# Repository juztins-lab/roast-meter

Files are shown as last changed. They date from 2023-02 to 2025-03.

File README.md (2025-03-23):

<!--
repo name: roast-meter
description: DIY roast meter guide
github name:  Juztins-Lab
link: https://github.com/juztins-lab/roast-meter
logo path: assets/logo.png
screenshot: 
twitter: your_username
email: justin@skitlabs.net
-->

<!-- PROJECT SHIELDS -->
[][contributors-url]
[][forks-url]
[][stars-url]
[][issues-url]
[][license-url]
<!-- [![LinkedIn][linkedin-shield]][linkedin-url] -->

<!-- PROJECT LOGO -->
<br />
<p align="center">
    <a href="https://github.com/juztins-lab/roast-meter">
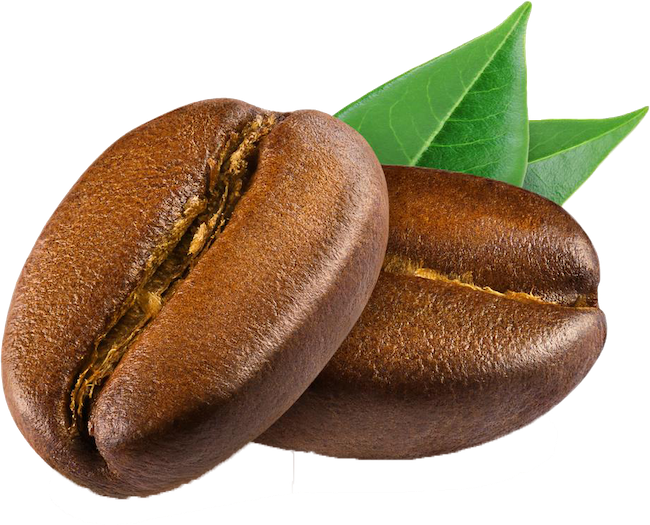
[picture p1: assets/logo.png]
        
    </a>
<h3 align="center"><a href="https://github.com/juztins-lab/roast-meter">Roast Meter</a></h3>
    <p align="center">
        An awesome DIY projects that will help you get better consistent roasts by measuring roast color between batches
        <br />
        <br />
        <a href="https://github.com/juztins-lab/roast-meter/issues">Report Bug</a>
        •
        <a href="https://github.com/juztins-lab/roast-meter/issues">Request Feature</a>
    </p>
</p>

<!-- TABLE OF CONTENTS -->
## Table of Contents

- [About The Project](#about-the-project)
- [Assembly Instructions](#assembly-instructions)
- [User Guide](#user-guide)
- [Calibration process](#calibration-process)
- [Roadmap](#roadmap)
- [Contributing](#contributing)
- [License](#license)
- [Contact](#contact)

<!-- ABOUT THE PROJECT -->
## About The Project

Starting into home roasting I've quickly realised the importance of a roast meter to evaluate the color of the coffee, this helps you better target different end temperature/time but retain the same level of color and see how it influences taste.

Here's why:
* Commercial grade roast meters are very expensive
* Chips and sensors are are readily available/cheap and easy to get going
* At the end of the guide you will have an ~100$ roast meter, that is consistent and can help you get the most out of your roast.

Check out our wiki for detailed instructions for assembly usage and calibration!

## Assembly Instructions
https://github.com/juztins-lab/roast-meter/wiki/Roast-Meter-Assembly-Instructions

## User Guide
https://github.com/juztins-lab/roast-meter/wiki/Roast-Meter-User's-Guide

## Calibration process
https://github.com/juztins-lab/roast-meter/wiki/Roast-Meter-User's-Guide#calibration-methods

<!-- ROADMAP -->
## Roadmap
* ~~Calibration against Agtron Gourmet Scale~~ (DONE)
* ~~Add battery, on/off button~~ (DONE)
* ~~Sensor calibration process - improved for consistency~~ (DONE)
* ~~Mobile application to store coffee roast information as well as roast level and history (bluetooth)~~ (BT version available but works with **external** web app)

See the [open issues](https://github.com/juztins-lab/roast-meter/issues) for a list of proposed features (and known issues).

<!-- CONTRIBUTING -->
## Contributing

Contributions are what make the open source community such an amazing place to be learn, inspire, and create. Any contributions you make are **greatly appreciated**.

1. Fork the Project
2. Create your Feature Branch (`git checkout -b feature/AmazingFeature`)
3. Commit your Changes (`git commit -m 'Add some AmazingFeature'`)
4. Push to the Branch (`git push origin feature/AmazingFeature`)
5. Open a Pull Request

<!-- LICENSE -->
## License

Distributed under the GNU License. See `LICENSE` for more information.

<!-- CONTACT -->
## Contact

Juztin - roastmeter@skitlabs.net

Project Link: [https://github.com/juztins-lab/roast-meter](https://github.com/juztins-lab/roast-meter)

<!-- MARKDOWN LINKS & IMAGES -->
<!-- https://www.markdownguide.org/basic-syntax/#reference-style-links -->
[contributors-shield]: https://img.shields.io/github/contributors/juztins-lab/roast-meter.svg?style=flat-square
[contributors-url]: https://github.com/juztins-lab/roast-meter/graphs/contributors
[forks-shield]: https://img.shields.io/github/forks/juztins-lab/roast-meter.svg?style=flat-square
[forks-url]: https://github.com/juztins-lab/roast-meter/network/members
[stars-shield]: https://img.shields.io/github/stars/juztins-lab/roast-meter.svg?style=flat-square
[stars-url]: https://github.com/juztins-lab/roast-meter/stargazers
[issues-shield]: https://img.shields.io/github/issues/juztins-lab/roast-meter.svg?style=flat-square
[issues-url]: https://github.com/juztins-lab/roast-meter/issues
[license-shield]: https://img.shields.io/github/license/juztins-lab/roast-meter.svg?style=flat-square
[license-url]: https://github.com/juztins-lab/roast-meter/blob/master/LICENSE.txt
[product-screenshot]: images/screenshot.png

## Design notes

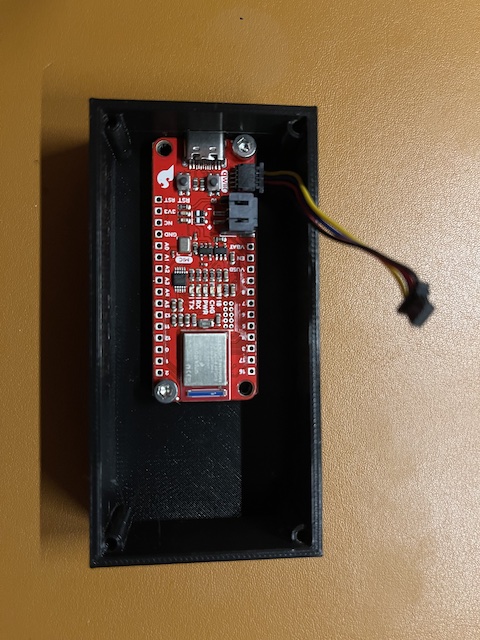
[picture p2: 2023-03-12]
assets/Case with board mounted.jpg

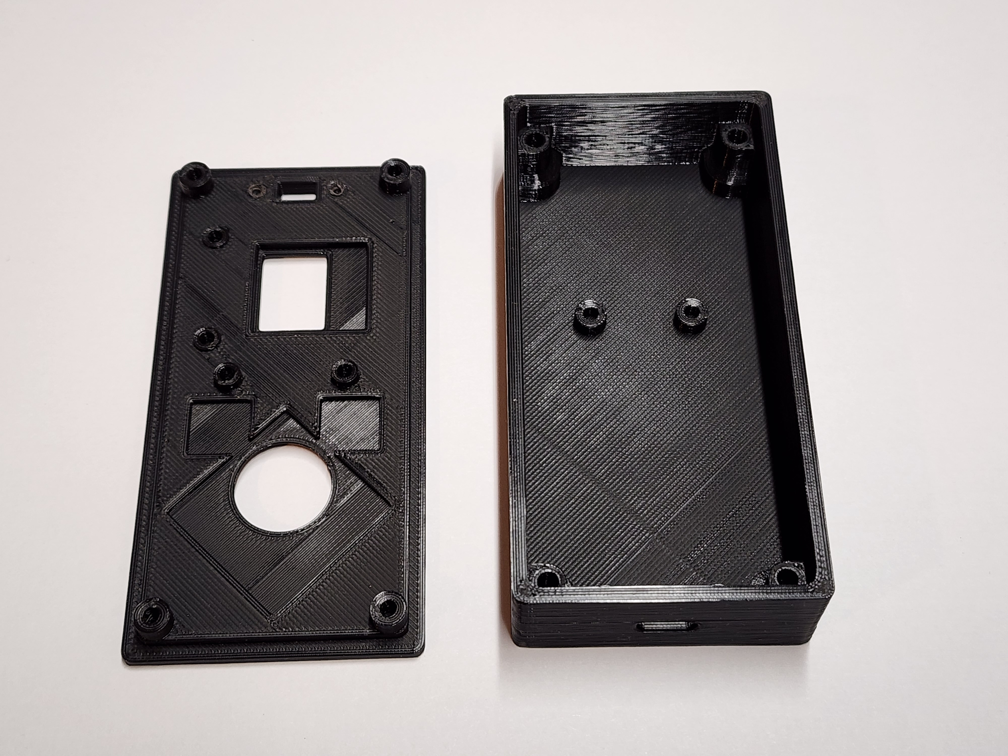
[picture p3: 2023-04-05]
assets/RM Case.jpg

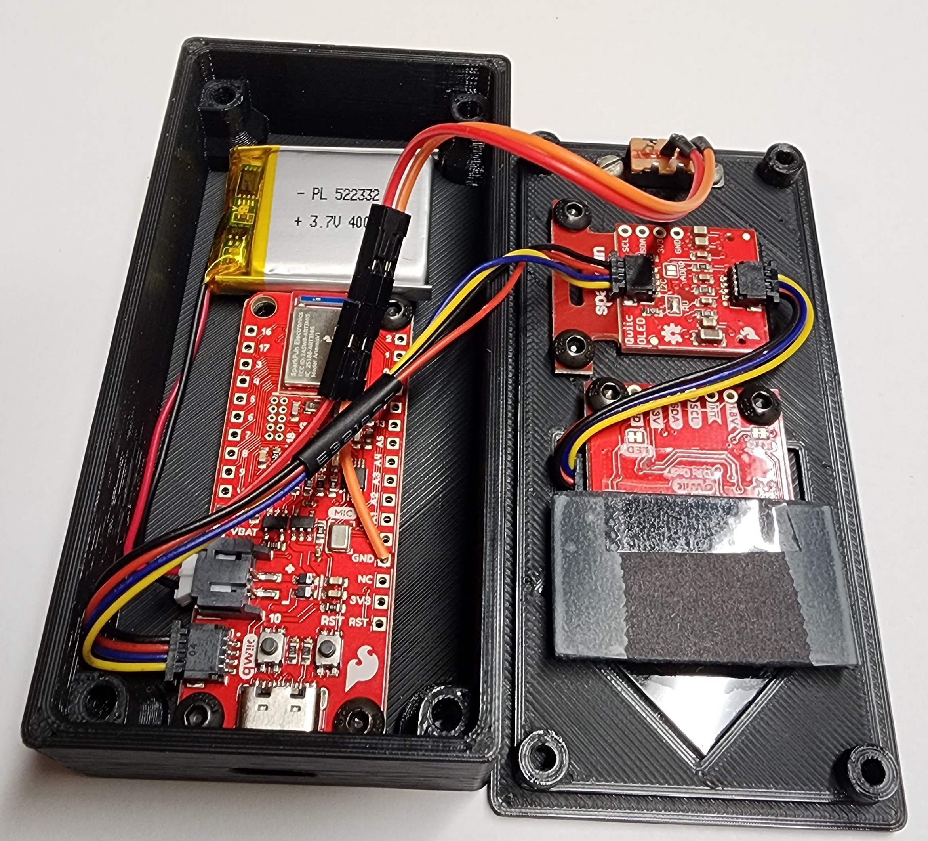
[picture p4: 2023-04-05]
assets/RM switch and battery.jpg

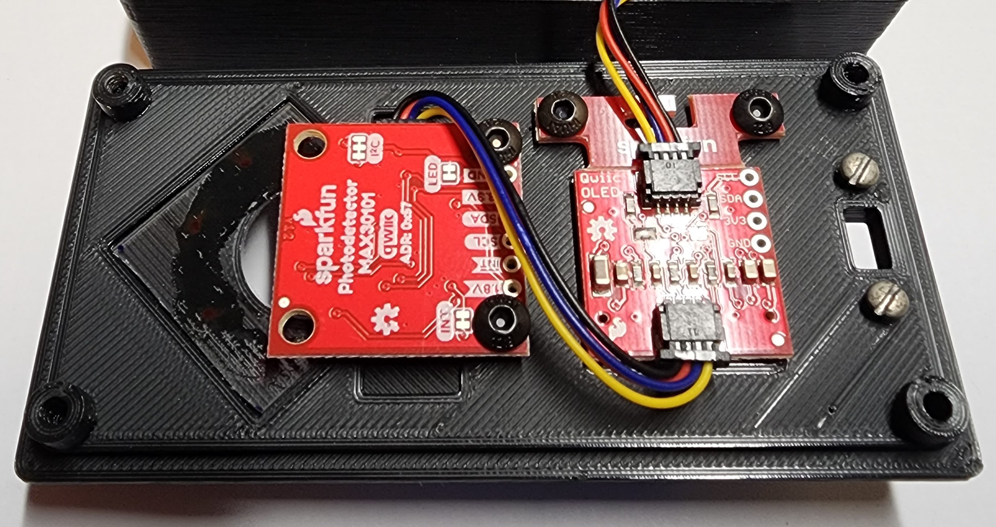
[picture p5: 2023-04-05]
assets/RM Lid CLose up.jpg

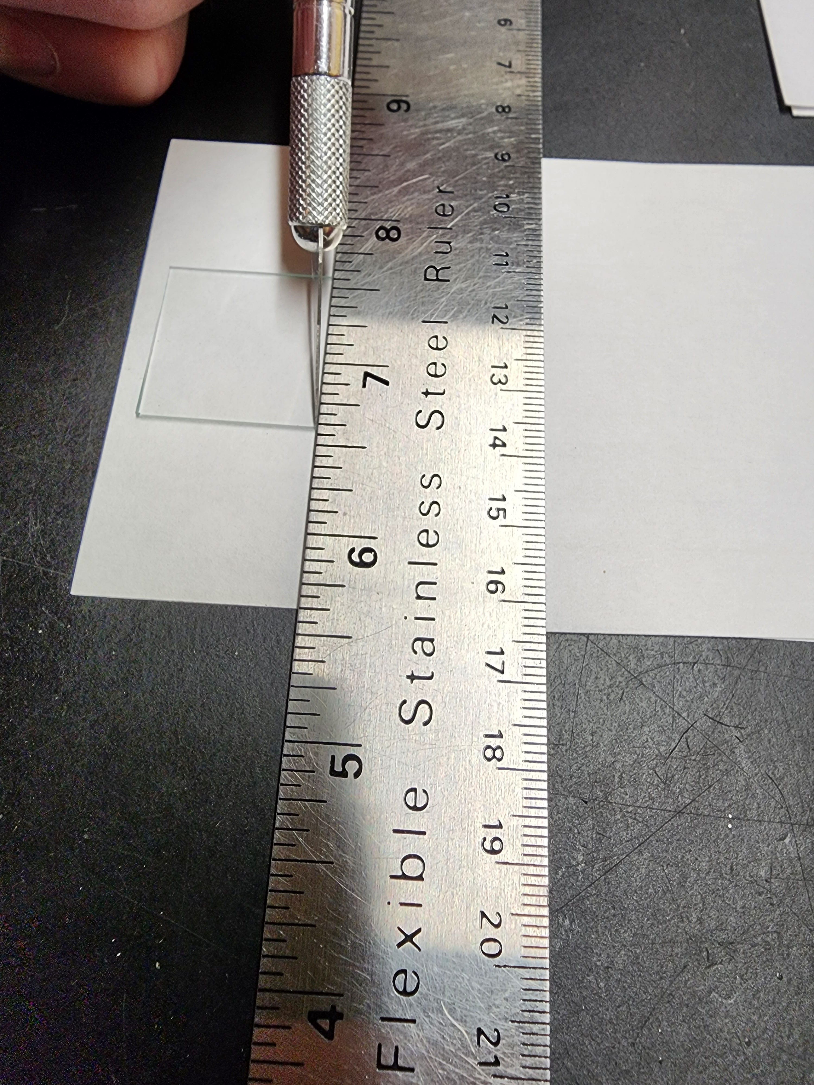
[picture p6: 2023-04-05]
assets/Cut Glass.jpg

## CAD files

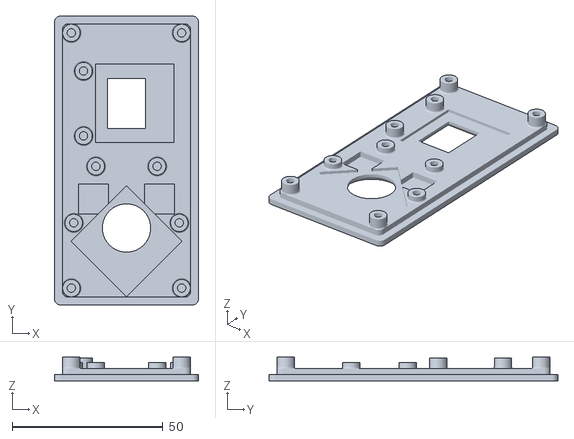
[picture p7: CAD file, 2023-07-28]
3D Print/Roast-Meter-Sensor-Tray-LID-NO-SWITCH-20230727.stl
47.8 x 95.8 x 7.80

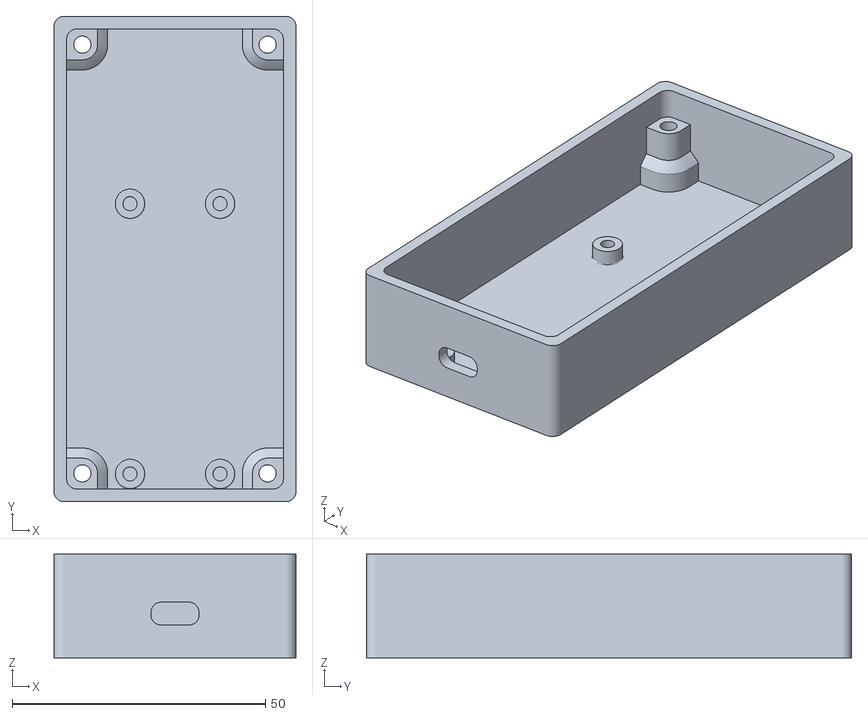
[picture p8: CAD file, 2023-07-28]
3D Print/Roast-Meter-Sensor-Tray-BASE-20230721.stl
47.8 x 95.8 x 20.5

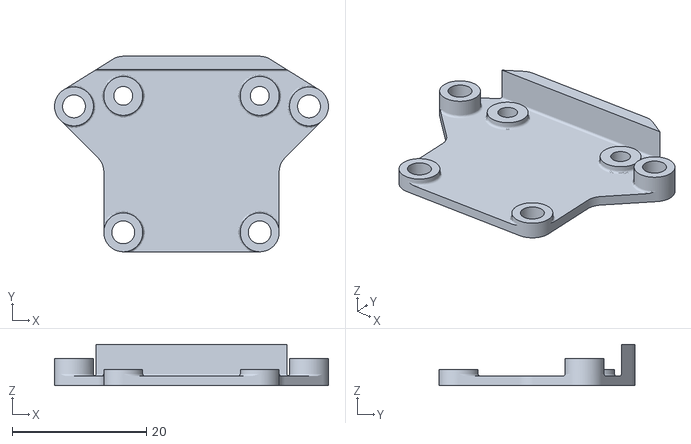
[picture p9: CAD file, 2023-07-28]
3D Print/Roast-Meter-Sensor-Tray-LID-TRAY-20230721.stl
40.8 x 29.1 x 6.11

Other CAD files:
3D Print/Roast-Meter-Sensor-Tray-LID-w-SWITCH-20230727.stl

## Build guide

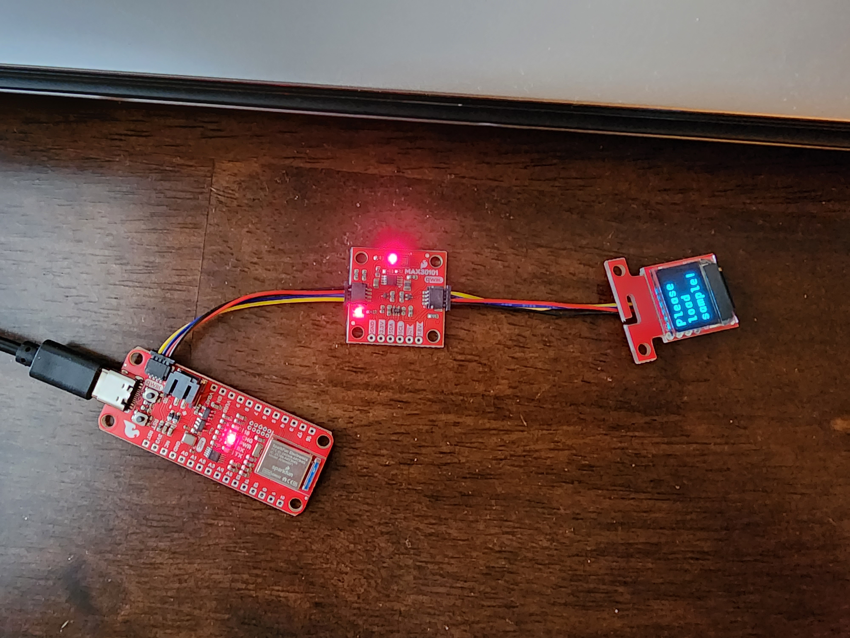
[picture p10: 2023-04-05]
assets/Assemble and Load Code.jpg

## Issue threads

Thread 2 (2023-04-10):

Suggested updates to roast_meter.ino

Brewzologist, 2023-04-10:
1) Cleaned up unused code that was commented out and/or not functional.
-- Rationale: make code easier to read and maintain.

2) Modified loop() to call getIR() one time per iteration so each rLevel is being tested AND displayed.
-- Rationale: each call to getIR() removes a sensor result from a FIFO queue.  Each iteration in loop() calls getIR(), tests it, then calls GetIR() again to display, so only every other sensor result is displayed.

3) Removed intToHex() function.
-- Rationale: you can assign a value directly to ledBrightness.  no need for this function.

4) Added ledBrightnessOffset calibration variable.
-- Rationale: using ledBrightness alone, which changes LED amplitude, is too coarse for calibration.  (e.g. changing it by +/- 1 causes as much as +6-7 points of Agtron reading change.)  So, created an additional variable affecting the Agtron conversion formula. This approach first allows calibration for sensor hardware differences, and then calibrates the Agtron conversion formula to a desired target value to addresss any remaining inconsistencies.  See comments in code.

5) Changed values passed to particleSensor.setup().  These are experimental but I'm not sure a high sample frequency is needed for measuring coffee vs the original intended use of the MAX30301 for HR/SPO2.
-- Rationale: optimizing MAX30101 sensor settings for coffee measurements.

6) After calling particleSensor.setup(), added overrides to specifically turn off all LED's and slots on the MAX30101 except for the IR LED.
-- Rationale: the code only calls getIR(), and in testing the red LED had no effect on the values returned by getIR() so turned it off.  Also disabled slots for red and green LEDs. Purpose is to optimize the MAX30101 LED settings for coffee measurements.

See code changes here:
[roast_meter_ino.zip](https://github.com/juztins-lab/roast-meter/files/11193078/roast_meter_ino.zip)

juztins-lab, 2023-04-19:
1,2,3 - OK
4. The idea of fine tuning is great and can be added later down the line, tho the implementation needs to offset the IR value not the converted result since the deviation becomes increasingly further from the scale in question.
5,6 Testing and calibration was done with the red led and proved better results, will need to revise this but at the moment this will not change, adjusted sampleRate and average to 50 and 4.

Closed 2023-04-19.

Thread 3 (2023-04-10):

Bottom v.2.0.3mf contains no models in Cura

wongcoder, 2023-04-10:
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
On attempting to open the .3mf, it will result in an error.

This isn't a major issue, as the other .stl file exists, but it is something to note.

nsolling, 2023-04-16:
Hi, I will check this.
There is still major work ongoing with the case - Although the version we have now is totally usable a few users are working on a more sturdy design.
I will just wait for that work to materialize before starting to fix up the potential issue.

nsolling, 2023-07-28:
Have removed the 3mf file and only publishes STL file as well as Fusion360 file now

Closed 2023-07-28.

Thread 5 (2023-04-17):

3D Lid Print without Switch?

motopreserve, 2023-04-17:
Sorry if I am asking this in the wrong place.  Forgive me if I'm being thick here - but I can't seem to find the 3D print file for use without the battery.

Love the project.  Thanks so much for all your work.

motopreserve, 2023-04-20:
Sorry, realized I was being confusing with the title.

nsolling, 2023-07-28:
HAs been updated

Closed 2023-07-28.

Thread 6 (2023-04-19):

Should we round the calculated Agtron result?

Brewzologist, 2023-04-19:
The way the Agtron conversion function f() is written, any decimal places are truncated.  e.g. both 88.1 and 88.9 return 88 from this function.  Is this intended?

I added the round() function before returning from f() so it will round the Agtron result to the closest integer. example:

return round((x - (intersectionPoint - x) * deviation) + ledBrightnessOffset);

juztins-lab, 2023-04-19:
Round is good.
Will apply the suggestion, it will not affect the current precision and allowed variation of 1-3 levels for the same roast level.

Closed 2023-04-19.

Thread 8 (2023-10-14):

LCD-14532 replaced with LCD-22495

wadeduvall, 2023-10-14:
The LCD-14532 has been replaced with [LCD-22495](https://www.sparkfun.com/products/22495). I'm guessing this can be replaced without any action but you might want to update your link in the parts list.

nsolling, 2023-10-20:
Hi, thanks for noticing and reporting - I looked at the specs and it looks identical.
When you get your hands on it do you mind reverting if it works (I think it will)

wadeduvall, 2023-10-20:
Hi @nsolling, yes, of course! I have the parts coming in this weekend and I hope to at least have it wired up on the benchtop for testing. Will report back!

wadeduvall, 2023-11-19:
@nsolling apologies for the delay, I had to get a replacement Thing Plus as the first one was DOA. I can confirm it's good to go!

wadeduvall, 2024-03-03:
Okay, I finally did the final assembly and am reopening this issue. It appears that the hole spacing on the new screen is a mm or two different.

Adminiuga, 2024-07-11:
I've just ordered the new part and printed the lid a few days ago. I can confirm the whole is about 1mm off. I'll take some measurements after I disassemble it.

Adminiuga, 2024-07-11:
Here is the picture of mine 22495 OLED. Seems like the distance is about 21mm

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

Closeup
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

csawtelle, 2024-09-09:
Same issue here I just assembled mine and the spacing is a little off. Worth noting that the screws still fit they just went in a tiny bit crooked. Everything works though!

Closed 2025-03-23.

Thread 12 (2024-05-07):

code installation software not working

giangian1, 2024-05-07:
hi guys, i am trying to install the software into my device but isn t working, I am following all the steps but nothing.  Is there a video to follow instructions?

giangian1, 2024-05-07:
it keep saying: Compilation error: SFE_MicroOLED.h: No such file or directory

wadeduvall, 2024-08-31:
Did you add the libraries for the OLED as described [here](https://learn.sparkfun.com/tutorials/installing-an-arduino-library)?

giangian1, 2024-09-08:
Yes sorted, thanks for asking

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

Closed 2024-09-08.

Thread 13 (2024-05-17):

Progress bar in loading mode

2571113, 2024-05-17:
Hello

I built the Roast Meter in the battery version. Everything seems to work as planned.
I can measure the tanning progress of the skin after a day in the mountains or at the beach.
It would be nice and helpful if there was a progress indicator for the charging mode.

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

juztins-lab, 2024-05-18:
Hi, thank you!
Unfortunately the hardware does not support it, additional steps is required and it raises complexity and probably the size a bit.
The yellow led indicates if its charging and it closes when its full.
Also battery lifetime is a couple of months on my usage of about 10 measurements a week.

Closed 2024-05-18.

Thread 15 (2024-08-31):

Instructions for calibration with sodium bicarbonate unclear

wadeduvall, 2024-08-31:
Instructions state "Apply a heaping amount to the sensor so that little red light shows through." Depending on what little means, I can get a variety of readings. If I completely block it out such that i can't see any red light, I get ~260. Is this the value I should be calibrating off of? If I adjust it so that a tiny bit of red light escapes, then I get almost exactly 230.  But it varies wildly based on how thick exactly the bed of bicarb is. If you truly mean no light, I would recommend updating it to read "Apply a heaping amount to the sensor so that no red light shines through"

Brewzologist, 2024-10-13:
Modified manual to say that no light passes thru.

Closed 2024-10-13.

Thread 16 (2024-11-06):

SparkFun Thing Plus - Artemis Sold out

jacewheelergitdeez, 2024-11-06:
Currently the board listed in the BOM is sold out.  Is there a potential alternative that would work with the code? Delete if this is the wrong spot for this sorry :)

juztins-lab, 2025-03-23:
Theoretically any arduino sparkfun with qwiic should work.

Closed 2025-03-23.

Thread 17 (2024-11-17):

LED Light is outside the glass circle.

acarr123, 2024-11-17:
I recently built my roast meter but the led light is shining outside the sensor area so I’m not sure how to calibrate it since the coffee doesn't cover the led light.
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

juztins-lab, 2024-11-17:
hi, led is IR, you won't see it, the other one is the power led, you can ignore it. Please follow the calibration instructions as per the guide, using bicarb and adjusting the ledBrightness variable till you read 230.

PS. I removed mentions of the red light from the documentation, that was an old reference when the sensor red light led was enabled, it is not the case anymore.

Closed 2024-11-17.

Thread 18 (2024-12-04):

Attribution

halveez, 2024-12-04:
I’m glad to see someone trying to open source roast level sensors but you should update your documentation to heavily attribute your design to Espresso Vision’s Roast Vision.

The parts used are identical, the 3D print is a direct copy, and my design was the first to use a top loaded sample which was read through a clear medium rather than a top down sensor design.

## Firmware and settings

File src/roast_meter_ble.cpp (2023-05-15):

// VERSION 1.0.0
#include <ArduinoBLE.h>
#include <EEPROM.h>
#include <SFE_MicroOLED.h>
#include <Wire.h>

#include "MAX30105.h"

// -- Constant Values --
#define FIRMWARE_REVISION_STRING "v0.1"

#define PIN_RESET 9
#define DC_JUMPER 1

#define BLE_UUID_ROAST_METER_SERVICE "875A0EE0-03DD-4225-AE06-35E8AE92B84C"
#define BLE_UUID_PARTICLE_SENSOR "C32AFDBA-E9F2-453E-9612-85FBF4108AB2"
#define BLE_UUID_AGTRON "CE216811-0AD9-4AFF-AE29-8B171093A95F"
#define BLE_UUID_METER_STATE "8ACE2828-996F-48E4-8E9C-8284678B4B57"

#define BLE_UUID_DEVICE_INFOMATION_SERVICE "180A"
#define BLE_UUID_FIRMWARE_REVISION "2A26"

#define BLE_UUID_SETTING_SERVICE "59021473-DFC6-425A-9729-09310EBE535E"
#define BLE_UUID_LED_BRIGHTNESS "8313695F-3EA1-458B-BD2A-DF4AEE218514"
#define BLE_UUID_INTERSECTION_POINT "69548C4B-87D0-4E3E-AC6C-B143C7B2AB30"
#define BLE_UUID_DEVIATION "D17234FA-0F48-429A-9E9B-F5DB774EF682"
#define BLE_UUID_BLE_NAME "CDE44FD7-4C1E-42A0-8368-531DC87F6B56"
#define BLE_UUID_UNBLOCK_LEVEL "B8BEFA0C-FFDD-4096-9ACD-208657B4B73C"

#define STATE_SETUP 0
#define STATE_WARMUP 1
#define STATE_READY 2
#define STATE_MEASURED 3

// -- End Constant Values --

// -- EEPROM constants --

#define EEPROM_MAX_LENGTH 256                  // 1024 bytes
#define EEPROM_VALID_IDX 0                     // 1 byte
#define EEPROM_VALID_CODE (0xAA)               // uint8
#define EEPROM_LED_BRIGHTNESS_IDX 1            // 1 byte
#define EEPROM_LED_BRIGHTNESS_DEFAULT 135      // uint8
#define EEPROM_INTERSECTION_POINT_IDX 2        // 1 byte
#define EEPROM_INTERSECTION_POINT_DEFAULT 117  // uint8
#define EEPROM_DEVIATION_IDX 3                 // 1 byte
#define EEPROM_DEVIATION_DEFAULT 0.165f        // float 32 bit 4 bytes
#define EEPROM_BLE_NAME_IDX 128                // 64 byte - 1 byte length + 63 ASCII

// -- End EEPROM constants

// -- Global Variables --

uint32_t unblockedValue = 30000;  // Average IR at power up

MAX30105 particleSensor;
MicroOLED oled(PIN_RESET, DC_JUMPER);

// -- End Global Variables --

// -- Global Setting --

// The variable below calibrates the LED output on your hardware.
byte ledBrightness;      // !EEPROM setup
byte sampleAverage = 4;  // Options: 1, 2, 4, 8, 16, --32--
byte ledMode = 2;        // Options: 1 = Red only, --2 = Red + IR--, 3 = Red + IR + Green
int sampleRate = 50;     // Options: 50, 100, 200, 400, 800, 1000, 1600, --3200--
int pulseWidth = 411;    // Options: 69, 118, 215, --411--
int adcRange = 16384;    // Options: 2048, 4096, 8192, --16384--

// The variable below use to calculate Agtron from IR
int intersectionPoint = 117;  // !EEPROM setup
float deviation = 0.165;      // !EEPROM setup

// BLE
String bleName;  // !EEPROM setup

// -- End Global Setting --

// -- Setup Headers --

void setupEEPROM();
void setupBLE();
void setupParticleSensor();

// -- Setup Headers --

// -- Sub Routine Headers --

void displayStartUp();
void warmUpLED();
void measureSampleJob();
void displayPleaseLoadSample();
void displayMeasurement(int rLevel);

// -- End Sub Routine Headers --

// -- BLE Function Headers --
BLEService roastMeterService(BLE_UUID_ROAST_METER_SERVICE);

BLEDescriptor particleSensorDescriptor("2901", "particle_sensor");
BLEUnsignedIntCharacteristic particleSensorCharacteristic(BLE_UUID_PARTICLE_SENSOR, BLERead | BLENotify);

BLEDescriptor agtronDescriptor("2901", "agtron");
BLEByteCharacteristic agtronCharacteristic(BLE_UUID_AGTRON, BLERead | BLENotify);

BLEDescriptor meterStateDescriptor("2901", "meter_state");
BLEByteCharacteristic meterStateCharacteristic(BLE_UUID_METER_STATE, BLERead | BLENotify);

BLEService settingService(BLE_UUID_SETTING_SERVICE);

BLEDescriptor ledBrightnessLevelDescriptor("2901", "led_brightness_level");
BLEByteCharacteristic ledBrightnessLevelCharacteristic(BLE_UUID_LED_BRIGHTNESS, BLERead | BLEWrite);

BLEDescriptor intersectionPointDescriptor("2901", "intersection_point");
BLEByteCharacteristic intersectionPointCharacteristic(BLE_UUID_INTERSECTION_POINT, BLERead | BLEWrite);

BLEDescriptor deviationDescriptor("2901", "deviation");
BLEFloatCharacteristic deviationCharacteristic(BLE_UUID_DEVIATION, BLERead | BLEWrite);

BLEDescriptor bleNameDescriptor("2901", "ble_name");
BLEStringCharacteristic bleNameCharacteristic(BLE_UUID_BLE_NAME, BLERead | BLEWrite, 64);

BLEService deviceInfomationService(BLE_UUID_DEVICE_INFOMATION_SERVICE);
BLEStringCharacteristic firmwareRevisionCharacteristic(BLE_UUID_FIRMWARE_REVISION, BLERead | BLEWrite, 64);

// -- End BLE Function Headers --

// -- BLE Handler Headers --

void blePeripheralConnectHandler(BLEDevice central);
void blePeripheralDisconnectHandler(BLEDevice central);

void bleLEDBrightnessLevelWriten(BLEDevice central, BLECharacteristic characteristic);
void bleIntersectionPointWriten(BLEDevice central, BLECharacteristic characteristic);
void bleDeviationWriten(BLEDevice central, BLECharacteristic characteristic);
void bleBLENameWriten(BLEDevice central, BLECharacteristic characteristic);

// -- End BLE Handler Headers --

// -- Utility Function Headers --

String multiplyChar(char c, int n);
String stringLastN(String input, int n);
int mapIRToAgtron(int x);
void writeStringToEEPROM(int addrOffset, const String &strToWrite);
String readStringFromEEPROM(int addrOffset);

// -- End Utillity Function Headers --

// -- Main Process --
void setup() {
  Serial.begin(9600);

  BLE.begin();

  Wire.begin();

  oled.begin();      // Initialize the OLED
  oled.clear(ALL);   // Clear the display's internal memory
  oled.clear(PAGE);  // Clear the buffer.

  setupEEPROM();
  setupBLE();

  // Initialize sensor
  if (particleSensor.begin(Wire, I2C_SPEED_FAST) == false)  // Use default I2C port, 400kHz speed
  {
    Serial.println("MAX30105 was not found. Please check wiring/power. ");
    while (1)
      ;
  }

  setupParticleSensor();

  displayStartUp();
  warmUpLED();
}

void loop() {
  measureSampleJob();
  BLE.poll();
}

// -- End Main Process --

// -- Setups --

void setupEEPROM() {
  EEPROM.init();
  // You may choose to enable more or less EEPROM -
  // Default length is 1024 bytes (if setLength is not called)
  EEPROM.setLength(EEPROM_MAX_LENGTH);
  // Note: larger sizes will increase RAM usage and execution time

  // use EEPROM.get(int index, T type) to retrieve
  // an arbitrary type from flash memory
  uint8_t eeprom_valid;
  EEPROM.get(EEPROM_VALID_IDX, eeprom_valid);

  if (eeprom_valid != EEPROM_VALID_CODE) {
    Serial.println("EEPROM was invalid");

    // use EEPROM.put(int index, T type) to store
    // a variable in psuedo-eeprom flash memory
    // use a variable with a type so that EEPROM
    // knows how much memory to use
    uint8_t code_to_store = EEPROM_VALID_CODE;
    EEPROM.put(EEPROM_VALID_IDX, code_to_store);

    // store default LED brightness value in EEPROM
    uint8_t led_brightness_to_store = EEPROM_LED_BRIGHTNESS_DEFAULT;
    EEPROM.put(EEPROM_LED_BRIGHTNESS_IDX, led_brightness_to_store);

    // store default intersection point value in EEPROM
    uint8_t intersection_point_to_store = EEPROM_INTERSECTION_POINT_DEFAULT;
    EEPROM.put(EEPROM_INTERSECTION_POINT_IDX, intersection_point_to_store);

    // store default deviation value in EEPROM
    float deviation_to_store = EEPROM_DEVIATION_DEFAULT;
    EEPROM.put(EEPROM_DEVIATION_IDX, deviation_to_store);

    // store default BLE name in EEPROM
    BLE.begin();
    String ble_name_to_store = "Roast Meter " + stringLastN(BLE.address(), 5);
    writeStringToEEPROM(EEPROM_BLE_NAME_IDX, ble_name_to_store);

    Serial.println("EEPROM initialized");
  }

  EEPROM.get(EEPROM_VALID_IDX, eeprom_valid);
  if (eeprom_valid != EEPROM_VALID_CODE) {
    Serial.println("EEPROM CAN NOT initialized");
    while (1) {
    };
  }

  Serial.println("EEPROM is valid");

  // Load setting from EEPROM

  uint8_t eeprom_led_brightness;
  EEPROM.get(EEPROM_LED_BRIGHTNESS_IDX, eeprom_led_brightness);
  ledBrightness = eeprom_led_brightness;
  Serial.println("Set ledBrightness to " + String(ledBrightness));

  uint8_t eeprom_intersection_point;
  EEPROM.get(EEPROM_INTERSECTION_POINT_IDX, eeprom_intersection_point);
  intersectionPoint = eeprom_intersection_point;
  Serial.println("Set intersection point to " + String(intersectionPoint));

  float eeprom_deviation;
  EEPROM.get(EEPROM_DEVIATION_IDX, eeprom_deviation);
  deviation = eeprom_deviation;
  Serial.print("Set deviation to ");
  Serial.print(deviation);
  Serial.println();

  bleName = readStringFromEEPROM(EEPROM_BLE_NAME_IDX);
  Serial.println("Set BLE name to " + String(bleName));
}

void setupBLE() {
  if (!BLE.begin()) {
    Serial.println("starting Bluetooth® Low Energy module failed!");
  }

  // set the local name peripheral advertises
  BLE.setLocalName(bleName.c_str());
  BLE.setDeviceName(bleName.c_str());
  // set the UUID for the service this peripheral advertises
  BLE.setAdvertisedService(roastMeterService);

  // add the characteristic to the service
  roastMeterService.addCharacteristic(particleSensorCharacteristic);
  roastMeterService.addCharacteristic(agtronCharacteristic);
  roastMeterService.addCharacteristic(meterStateCharacteristic);

  settingService.addCharacteristic(ledBrightnessLevelCharacteristic);
  settingService.addCharacteristic(intersectionPointCharacteristic);
  settingService.addCharacteristic(deviationCharacteristic);
  settingService.addCharacteristic(bleNameCharacteristic);

  deviceInfomationService.addCharacteristic(firmwareRevisionCharacteristic);

  // add service
  BLE.addService(roastMeterService);
  BLE.addService(settingService);
  BLE.addService(deviceInfomationService);

  // assign event handlers for connected, disconnected to peripheral
  BLE.setEventHandler(BLEConnected, blePeripheralConnectHandler);
  BLE.setEventHandler(BLEDisconnected, blePeripheralDisconnectHandler);

  agtronCharacteristic.addDescriptor(agtronDescriptor);
  particleSensorCharacteristic.addDescriptor(particleSensorDescriptor);
  meterStateCharacteristic.addDescriptor(meterStateDescriptor);

  ledBrightnessLevelCharacteristic.addDescriptor(ledBrightnessLevelDescriptor);
  ledBrightnessLevelCharacteristic.setEventHandler(BLEWritten, bleLEDBrightnessLevelWriten);

  intersectionPointCharacteristic.addDescriptor(intersectionPointDescriptor);
  intersectionPointCharacteristic.setEventHandler(BLEWritten, bleIntersectionPointWriten);

  deviationCharacteristic.addDescriptor(deviationDescriptor);
  deviationCharacteristic.setEventHandler(BLEWritten, bleDeviationWriten);

  bleNameCharacteristic.addDescriptor(bleNameDescriptor);
  bleNameCharacteristic.setEventHandler(BLEWritten, bleBLENameWriten);

  // Assign current value and setting for BLE Characteristic
  particleSensorCharacteristic.setValue(0);
  agtronCharacteristic.setValue(0);
  meterStateCharacteristic.setValue(STATE_SETUP);

  ledBrightnessLevelCharacteristic.setValue(ledBrightness);
  intersectionPointCharacteristic.setValue(intersectionPoint);
  deviationCharacteristic.setValue(deviation);
  bleNameCharacteristic.setValue(bleName);

  firmwareRevisionCharacteristic.writeValue(FIRMWARE_REVISION_STRING);

  // start advertising
  BLE.advertise();

  Serial.println(("Bluetooth® device active, waiting for connections..."));
}

void setupParticleSensor() {
  particleSensor.setup(ledBrightness, sampleAverage, ledMode, sampleRate, pulseWidth, adcRange);  // Configure sensor with these settings

  particleSensor.setPulseAmplitudeRed(0);
  particleSensor.setPulseAmplitudeGreen(0);

  particleSensor.disableSlots();
  particleSensor.enableSlot(2, 0x02);  // Enable only SLOT_IR_LED = 0x02
}

// -- End Setups --

// Sub Routines

void displayStartUp() {
  oled.clear(PAGE);
  oled.setCursor(0, 0);
  oled.setFontType(1);
  oled.print("Roast  ");
  oled.print("Meter  ");
  oled.print(FIRMWARE_REVISION_STRING);
  oled.display();

  delay(2000);

  oled.clear(PAGE);
  oled.setCursor(0, 0);
  oled.setFontType(1);
  oled.print(bleName);
  oled.display();

  delay(2000);
}

void warmUpLED() {
  meterStateCharacteristic.writeValue(STATE_WARMUP);

  int countDownSeconds = 60;
  unsigned long jobTimerStart = millis();
  unsigned long jobTimer = jobTimerStart;

  while (millis() - jobTimerStart <= 60 * 1000) {
    unsigned long elapsed = millis() - jobTimer;

    if (elapsed > 100) {
      oled.clear(PAGE);
      oled.setCursor(0, 0);
      oled.setFontType(1);

      countDownSeconds = 60 - ((millis() - jobTimerStart) / 1000);

      oled.print("Warm Up " + String(countDownSeconds) + "s");
      oled.display();

      jobTimer = millis();
    }

    BLE.poll();
  }
}

unsigned long measureSampleJobTimer = millis();
void measureSampleJob() {
  if (millis() - measureSampleJobTimer > 100) {
    int rLevel = particleSensor.getIR();
    long currentDelta = (long)rLevel - (long)unblockedValue;

    if (currentDelta > (long)100) {
      int calibratedAgtronLevel = mapIRToAgtron(rLevel / 1000);

      agtronCharacteristic.writeValue(calibratedAgtronLevel);
      particleSensorCharacteristic.writeValue(rLevel / 1000);
      meterStateCharacteristic.writeValue(STATE_MEASURED);

      displayMeasurement(calibratedAgtronLevel);

      Serial.println("real:" + String(rLevel));
      Serial.println("agtron:" + String(calibratedAgtronLevel));
      Serial.println("===========================");
    } else {
      agtronCharacteristic.writeValue(0);
      particleSensorCharacteristic.writeValue(0);
      meterStateCharacteristic.writeValue(STATE_READY);

      displayPleaseLoadSample();
    }

    measureSampleJobTimer = millis();
  }
}

void displayPleaseLoadSample() {
  oled.clear(PAGE);
  oled.setCursor(0, 0);
  oled.setFontType(1);
  oled.print("Please load   sample!");
  oled.display();
}

void displayMeasurement(int agtronLevel) {
  oled.clear(PAGE);
  oled.setCursor(0, 0);

  int centerPadding = 4 - String(agtronLevel).length();
  String paddingText = multiplyChar(' ', centerPadding);

  oled.setFontType(3);
  oled.print(paddingText);
  oled.print(agtronLevel);

  oled.display();
}

// -- End Sub Routines --

// -- BLE Handler --

void blePeripheralConnectHandler(BLEDevice central) {
  // central connected event handler
  Serial.print("BLE Connected event, central: ");
  Serial.println(central.address());
}

void blePeripheralDisconnectHandler(BLEDevice central) {
  // central disconnected event handler
  Serial.print("BLE Disconnected event, central: ");
  Serial.println(central.address());
}

void bleLEDBrightnessLevelWriten(BLEDevice central, BLECharacteristic characteristic) {
  ledBrightness = ledBrightnessLevelCharacteristic.value();

  Serial.print("bleLEDBrightnessLevelWriten event, written: ");
  Serial.println(ledBrightness);

  EEPROM.put(EEPROM_LED_BRIGHTNESS_IDX, ledBrightness);

  setupParticleSensor();
}

void bleIntersectionPointWriten(BLEDevice central, BLECharacteristic characteristic) {
  intersectionPoint = intersectionPointCharacteristic.value();

  Serial.print("bleIntersectionPointWriten event, written: ");
  Serial.println(intersectionPoint);

  EEPROM.put(EEPROM_INTERSECTION_POINT_IDX, intersectionPoint);
}

void bleDeviationWriten(BLEDevice central, BLECharacteristic characteristic) {
  deviation = deviationCharacteristic.value();

  Serial.print("bleDeviationWriten event, written: ");
  Serial.println(deviation);

  EEPROM.put(EEPROM_DEVIATION_IDX, deviation);
}

void bleBLENameWriten(BLEDevice central, BLECharacteristic characteristic) {
  String newBLEName = bleNameCharacteristic.value();

  if (newBLEName.length() > 63) {
    Serial.println("bleBLENameWriten event, written rejected!. String length exceed 63.");
    bleNameCharacteristic.setValue(bleName.c_str());

    return;
  }

  bleName = newBLEName;
  Serial.print("bleBLENameWriten event, written: ");
  Serial.println(bleName);

  BLE.setLocalName(bleName.c_str());
  BLE.setDeviceName(bleName.c_str());

  writeStringToEEPROM(EEPROM_BLE_NAME_IDX, bleName);
}

// -- End BLE Handler --

// -- Utillity Functions --

String multiplyChar(char c, int n) {
  String result = "";
  for (int i = 0; i < n; i++) {
    result += c;
  }
  return result;
}

String stringLastN(String input, int n) {
  int inputSize = input.length();

  return (n > 0 && inputSize > n) ? input.substring(inputSize - n) : "";
}

int mapIRToAgtron(int x) {
  return round(x - (intersectionPoint - x) * deviation);
}

// https://roboticsbackend.com/arduino-write-string-in-eeprom/
void writeStringToEEPROM(int addrOffset, const String &strToWrite) {
  byte len = strToWrite.length();
  EEPROM.write(addrOffset, len);
  for (int i = 0; i < len; i++) {
    EEPROM.write(addrOffset + 1 + i, strToWrite[i]);
  }
}

String readStringFromEEPROM(int addrOffset) {
  int newStrLen = EEPROM.read(addrOffset);
  char data[newStrLen + 1];

  for (int i = 0; i < newStrLen; i++) {
    data[i] = EEPROM.read(addrOffset + 1 + i);
  }
  data[newStrLen] = '\0';

  return String(data);
}

// -- End Utillity Functions --

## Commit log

2023-02-23 Added 3d case files (courtesy of Nicolai) Fixed typo
    [base.stl, top_with_for_M3x8mm_screws.stl, top_with_studs.stl]
2023-02-23 Delete 3d-prints/case-battery directory
    spelling mistake
    [Roast Meter with Battery Top.stl, Roast Meter with Battery bottom.stl]
2023-02-24 Create Print instructions
2023-03-11 Update roast_meter.ino
    Updated code calibrated to match better the agtron gourmet readings. Updated information display for better overall experience.
2023-03-12 Add files via upload
    Removed the pin access to the D10 switch on the Artemis board as no function currently implemented
    [Roast Meter TOP - No switch 1.3 stl.stl, Roast Meter TOP - w. Switch 1.3.stl]
2023-03-12 Pictures for assembly guide
2023-03-17 Add files via upload
    All the new print files based on the great work from @natewalk
    [Bottom v.2.0.3mf, Bottom v.2.0.stl, Lid w. Switch 2.0.stl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]
2023-03-17 Update Print instructions
2023-03-18 Add files via upload
    Added step and 3f design files as some users were asking to be able to modify the case
    [Roast Meter 2.0.step]
2023-03-30 Update calibration and incremented version to 1.0.0-rc.3
2023-05-09 add arduinoble and refactor
2023-07-15 Update Print instructions
    Updated print-instructions for the new lid design with a tray
2023-07-28 Add files via upload
    sync of files from https://github.com/PatrickFrN/roast-meter/tree/8629b0b8371019c9bcf1ba9bcac2703f6f5b38d9/3D%20Print/Parametric
    [Roast-Meter-Sensor-Tray-BASE-20230721.stl, Roast-Meter-Sensor-Tray-LID-NO-SWITCH-20230727.stl, Roast-Meter-Sensor-Tray-LID-TRAY-20230721.stl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]

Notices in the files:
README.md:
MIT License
